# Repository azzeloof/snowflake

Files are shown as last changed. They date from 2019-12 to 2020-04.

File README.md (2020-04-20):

# snowflake
 A PCB holiday ornament with lots of blinking LEDs!

## Hardware
The board consists of twelve reverse-mounted LEDs [charlieplexed](https://en.wikipedia.org/wiki/Charlieplexing) and hooked up to an ATtiny85. Each LED is individually addressable, even though only four of the ATtiny's pins are being used (Charlieplexing is magic)! The board also has a pushbutton for switching between modes. The ornament is powered via six CR1225 batteries.

The final board isn't the most elegant thing- there are several zero-ohm jumpers, and there's even a "decorative" wire that wraps around the snowflake that is actually a ground line I didn't want to route across the front of the ornament.

There is also a mistake in the current board files- under each LED should be a rectangle on the f.mask layer so that the area below the LED is free of solder mask. Instead, the rectangle is a keepout zone, which is useless in this situation. My solution was to scrape the areas clear with a knife but I don't recommend it because FR4 dust is nasty. The better solution is to fix the board files before ordering.

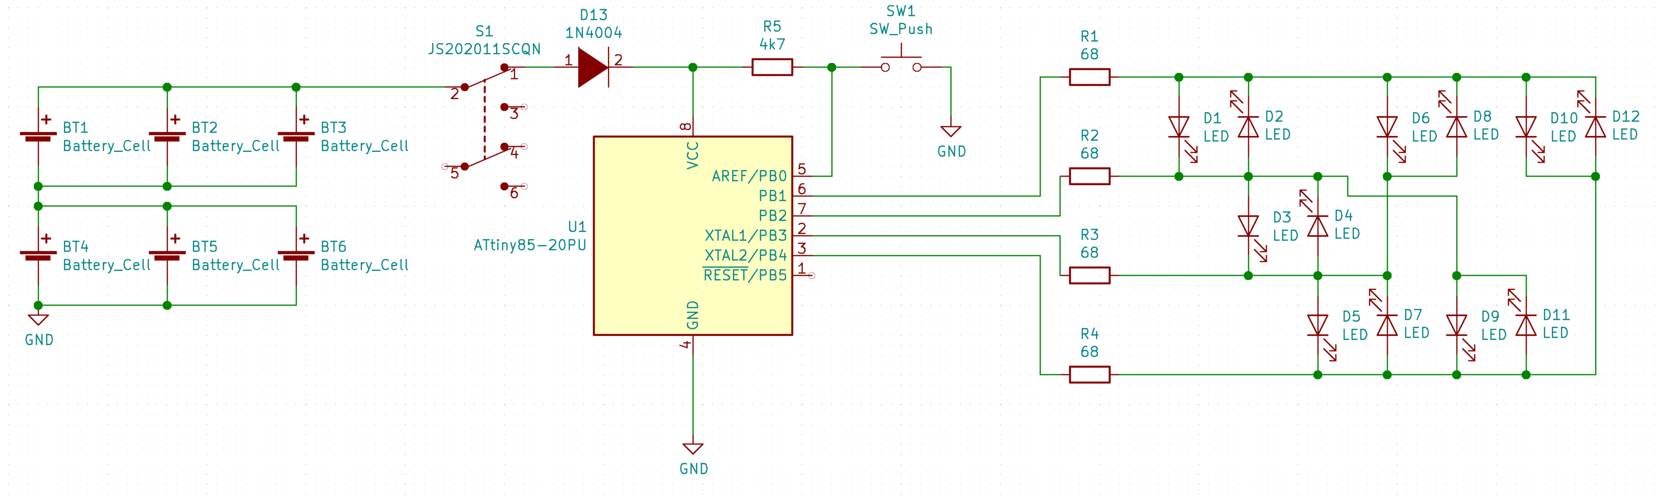
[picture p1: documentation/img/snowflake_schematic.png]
Snowflake Schematic


Board Front             |  Board Back
:-------------------------:|:-------------------------:
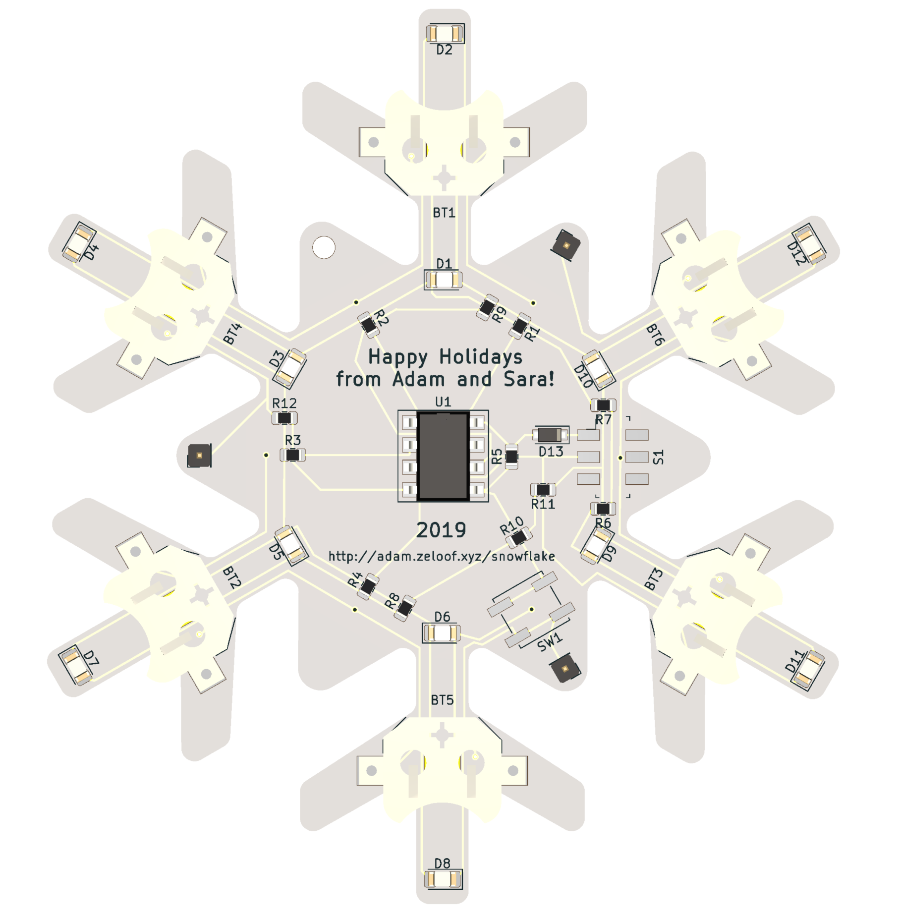
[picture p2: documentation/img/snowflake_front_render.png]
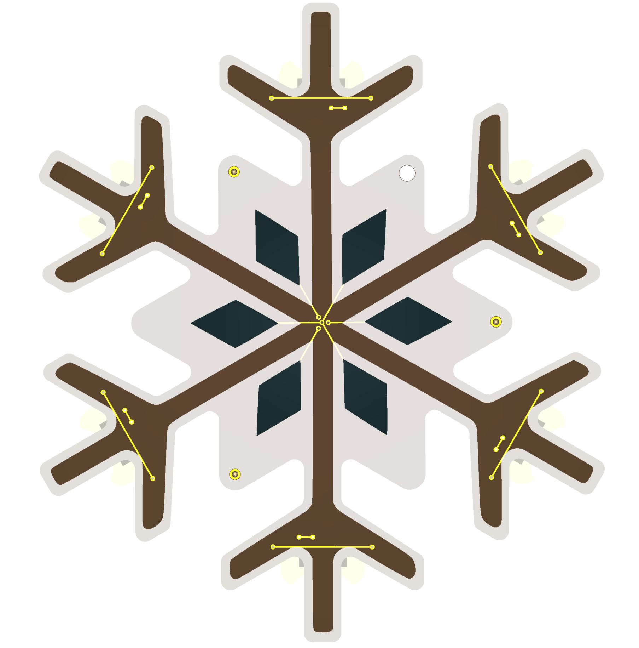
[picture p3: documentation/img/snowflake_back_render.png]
  |  

### BOM
A complete BOM can be found under [/documentation/snowflake_bom.csv](/documentation/snowflake_bom.csv), and can be uploaded to DigiKey for easy ordering. At the time of writing, the total DigiKey order is around $13. Boards can be ordered from anywhere that'll do white solder mask (I used PCBWay) and should be fairly cheap as well. You can order a stencil if desired, but I found it pretty easy to hand solder this one.

## (Firm?)(Soft?)ware
The ATtiny is programmed using the PlatformIO framework. Before programming, you need to write an Arduino bootloader to the chip using the Arduino IDE. When burning the bootloader, here are the settings we used:

+ Chip: "ATtiny85"
+ Clock: "8 MHz (internal)"
+ B.O.D: "B.O.D. Disabled"
+ Timer 1 Clock: "CPU"
+ LTO (1.6.11+ only): "Disabled"

The code is adapted from the wonderful work of David Johnson-Davies, published at http://www.technoblogy.com/show?2H0K.

To program the chips, we used SparkFun's [Pocket AVR Programmer](https://www.sparkfun.com/products/9825), but you should be able to use any programmer compatibe with the ATtiny85 (or just use an Arduino Uno!).

## Version History
Release 1.0 represents the snowflake ornaments as we initially made and distributed them. Once it is released, maybe we'll improve some stuff (but any hardware improvements will be untested).

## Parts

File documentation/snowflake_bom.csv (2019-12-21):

Manufacturer Part Number | Manufacturer | Digi-Key Part Number | Customer Reference | Reference Designator | Packaging | Part Status | Quantity | Unit Price | Extended Price | Quantity Available | Mfg Std Lead Time | Description | RoHS Status | Lead Free Status | REACH Status
ATTINY85-20PU | Microchip Technology | ATTINY85-20PU-ND |  |  | Tube | Active | 1 | 1.20000 | $1.20 | 424 | 7 Weeks | IC MCU 8BIT 8KB FLASH 8DIP | ROHS3 Compliant | Lead free | REACH Unaffected
114-87-308-41-134161 | Preci-Dip | 1212-1032-ND |  |  | Tube | Active | 1 | 0.57000 | $0.57 | 3379 | 10 Weeks | CONN IC DIP SOCKET 8POS GOLD | ROHS3 Compliant | Lead free | REACH Unaffected
JS202011SCQN | C&K | 401-2002-1-ND |  |  | Cut Tape (CT) | Active | 1 | 0.48000 | $0.48 | 63083 | 13 Weeks | SWITCH SLIDE DPDT 300MA 6V | ROHS3 Compliant | Lead free | REACH Unaffected
APTR3216PBC/A | Kingbright | 754-1169-1-ND |  |  | Cut Tape (CT) | Active | 12 | 0.47900 | $5.74 | 198739 | 9 Weeks | LED BLUE CLEAR CHIP SMD | ROHS3 Compliant | Lead free | REACH Unaffected
RMCF0805FT68R0 | Stackpole Electronics Inc | RMCF0805FT68R0CT-ND |  |  | Cut Tape (CT) | Active | 4 | 0.10000 | $0.40 | 54109 | 17 Weeks | RES 68 OHM 1% 1/8W 0805 | ROHS3 Compliant | Lead free | REACH Unaffected
RMCF0805ZT0R00 | Stackpole Electronics Inc | RMCF0805ZT0R00CT-ND |  |  | Cut Tape (CT) | Active | 7 | 0.10000 | $0.70 | 1039707 | 17 Weeks | RES 0 OHM JUMPER 1/8W 0805 | ROHS3 Compliant | Lead free | REACH Unaffected
RC0805FR-074K7L | Yageo | 311-4.70KCRCT-ND |  |  | Cut Tape (CT) | Active | 1 | 0.10000 | $0.10 | 4827587 | 16 Weeks | RES SMD 4.7K OHM 1% 1/8W 0805 | ROHS3 Compliant | Lead free | REACH Unaffected
PTS645SL50SMTR92 LFS | C&K | CKN9088CT-ND |  |  | Cut Tape (CT) | Active | 1 | 0.31000 | $0.31 | 123917 | 14 Weeks | SWITCH TACTILE SPST-NO 0.05A 12V | ROHS3 Compliant | Lead free | REACH Unaffected
3000 | Keystone Electronics | 36-3000-ND |  |  | Bulk | Active | 6 | 0.52000 | $3.12 | 4750 | 6 Weeks | BATTERY RETAINER COIN 12MM SMD | ROHS3 Compliant | Lead free | REACH Unaffected
SM4004PL-TP | Micro Commercial Co | SM4004PL-TPMSCT-ND |  |  | Cut Tape (CT) | Active | 1 | 0.20000 | $0.20 | 29958 | 12 Weeks | DIODE GEN PURP 400V 1A SOD123FL | ROHS3 Compliant | Lead free | REACH Unaffected

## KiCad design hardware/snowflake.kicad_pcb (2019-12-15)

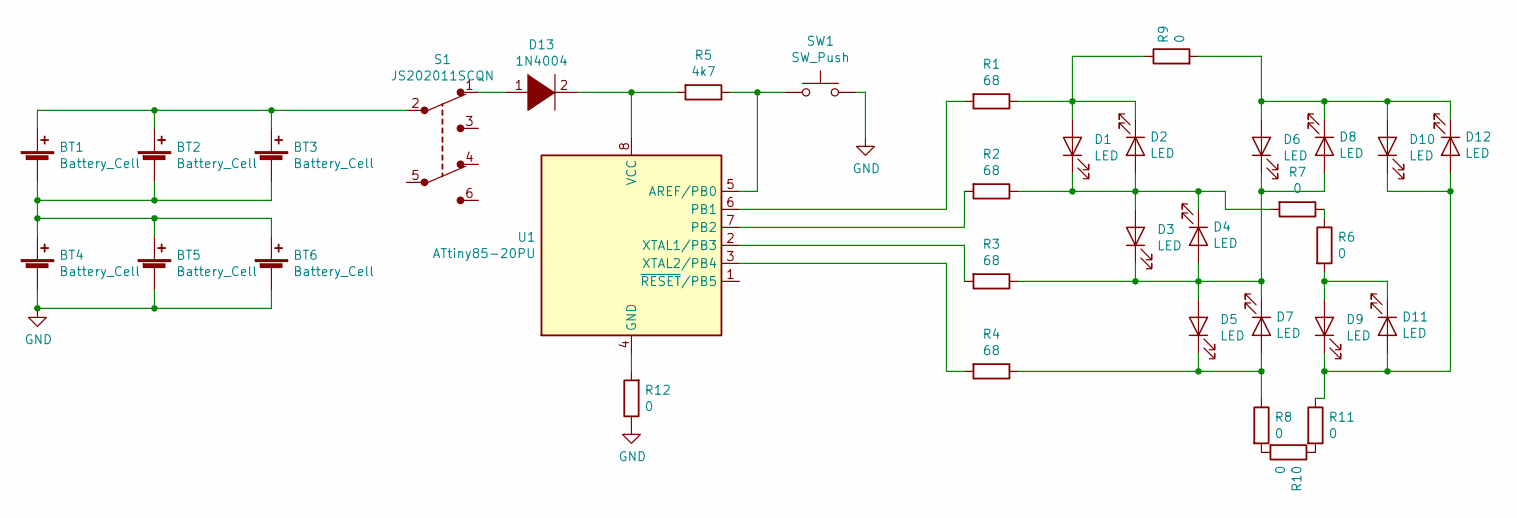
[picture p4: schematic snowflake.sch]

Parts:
BT1, BT2, BT3, BT4, BT5, BT6: Battery_Cell; BatteryHolder_Keystone_3000_1x12mm
D1, D2, D3, D4, D5, D6, D7, D8, D9, D10, D11, D12: LED; LED_1206_3216Metric
D13: 1N4004; D_SOD-123F
R1, R2, R3, R4: 68; R_0805_2012Metric
R5: 4k7; R_0805_2012Metric
R6, R7, R8, R9, R10, R11, R12: 0; R_0805_2012Metric
S1: JS202011SCQN; Switch_Slide_JS202011SCQN; MPN JS202011SCQN; Digi-Key_PN 401-2002-1-ND
SW1: SW_Push; SW_Push_1P1T_NO_CK_KSC6xxJ
U1: ATtiny85-20PU; DIP-8_W7.62mm_SMDSocket_SmallPads

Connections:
GND: BT4.2 (-), BT5.2 (-), BT6.2 (-), R12.1, SW1.2
unnamed: BT1.1 (+), BT2.1 (+), BT3.1 (+), S1.2
unnamed: BT1.2 (-), BT2.2 (-), BT3.2 (-), BT4.1 (+), BT5.1 (+), BT6.1 (+)
unnamed: D1.1 (K), D2.2 (A), D3.2 (A), D4.1 (K), R2.1, R7.2
unnamed: D1.2 (A), D2.1 (K), R1.1, R9.1
unnamed: D3.1 (K), D4.2 (A), D5.2 (A), D6.1 (K), D7.1 (K), D8.2 (A), R3.1
unnamed: D5.1 (K), D7.2 (A), R4.1, R8.1
unnamed: D9.1 (K), D10.1 (K), D11.2 (A), D12.2 (A), R11.1
unnamed: D6.2 (A), D8.1 (K), D10.2 (A), D12.1 (K), R9.2
unnamed: D9.2 (A), D11.1 (K), R6.2
unnamed: D13.1 (K), S1.1
unnamed: D13.2 (A), R5.2, U1.8 (VCC)
unnamed: R1.2, U1.6 (PB1)
unnamed: R2.2, U1.7 (PB2)
unnamed: R3.2, U1.2 (XTAL1/PB3)
unnamed: R4.2, U1.3 (XTAL2/PB4)
unnamed: R5.1, SW1.1, U1.5 (AREF/PB0)
unnamed: R6.1, R7.1
unnamed: R10.1, R11.2
unnamed: R8.2, R10.2
unnamed: R12.2, U1.4 (GND)

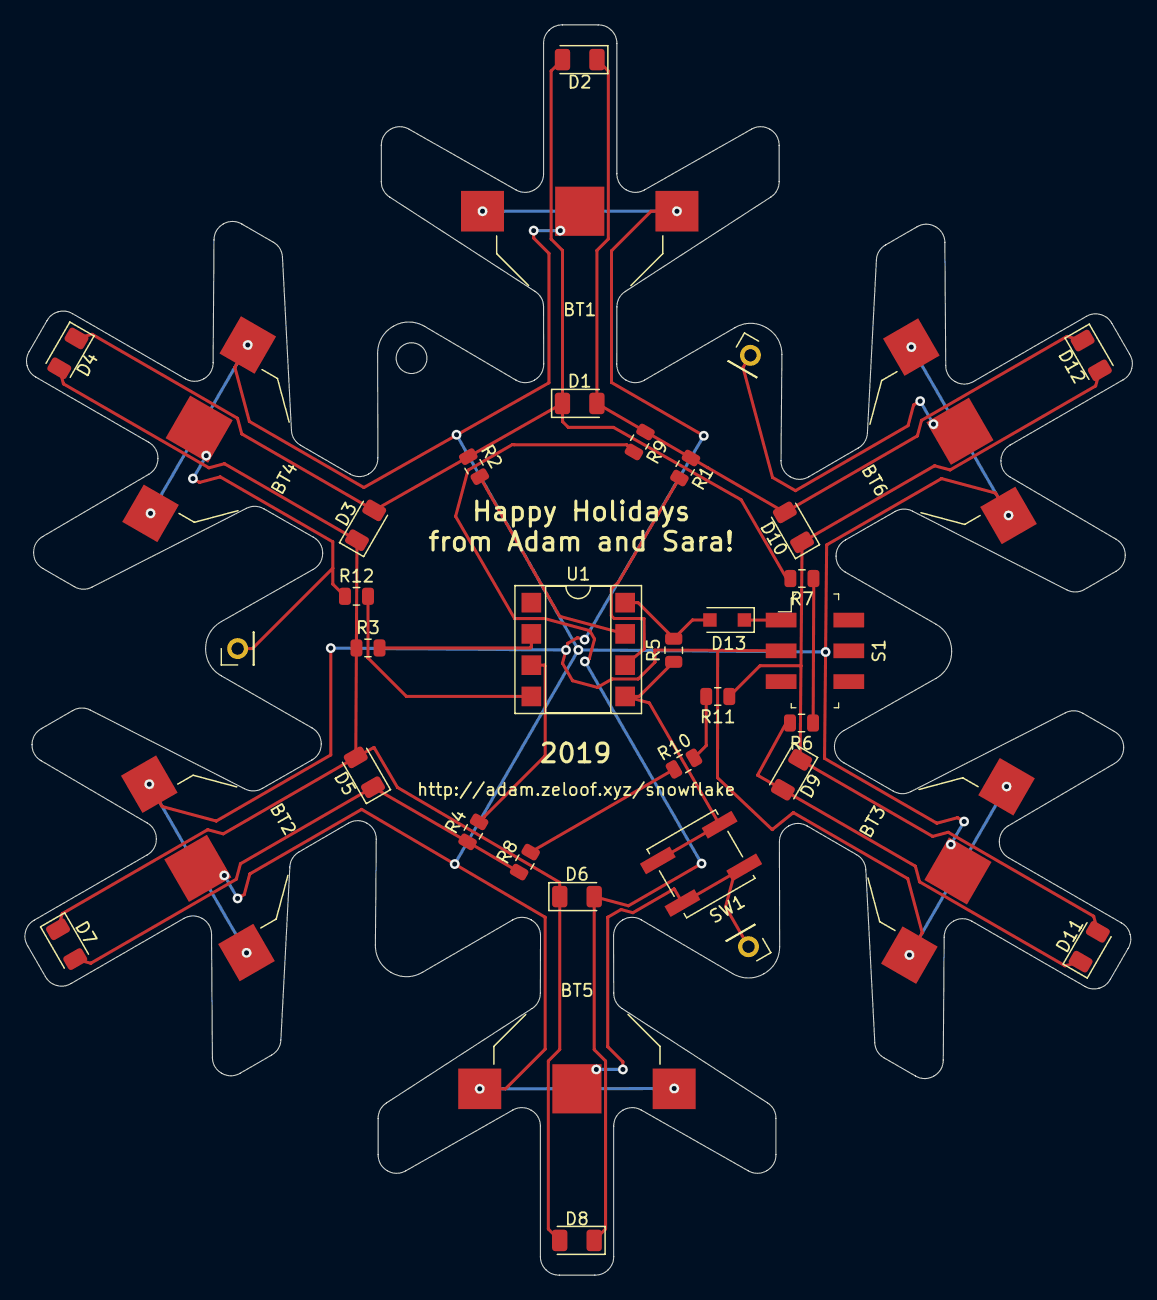
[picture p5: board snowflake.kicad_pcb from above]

Board: 2 copper layers, 90.0 x 101.6 mm, 34 parts (0 on the bottom side), 21 nets.

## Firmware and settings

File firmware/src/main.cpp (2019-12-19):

/*
 * Snowflake Christmas Ornament
 * 
 * Sara Adkins & Adam Zeloof - December 2019
 * 
 * PWM code adapted from David Johnson-Davies - www.technoblogy.com - 19th February 2017
 * http://www.technoblogy.com/show?2H0K
 */

#include "Arduino.h"
#include "modeButton.h"
#include "leds.h"
#include "ringFade.h"
#include "twinkle.h"
#include "chaos.h"

// Timer/Counter1 overflow interrupt
ISR(TIM1_COMPA_vect) {
  static uint8_t row, ramp, column, bits, colbit;
  ramp = (ramp+1) & 0x3F;             // Count from 0 to 63
  if (ramp == 0) {
    bits = 0x07; //0000111                    // All on
    column = (column + 1) & 0x03; // Count from 0 to 3
    row = column * 3;               //0 3 6 9
    colbit = 1<<(column+0); // 0b0001 0b0010 0b0100 0b1000
  }

  //check if check col has reached its ramp
  if (Level[row] == ramp) bits = bits & 0x06; // 00000110, mask out pos 0
  if (Level[row+1] == ramp) bits = bits & 0x05; // 00000101, mask out pos 1
  if (Level[row+2] == ramp) bits = bits & 0x03; // 00000011, mask out pos 2
  
  uint8_t mask = colbit - 1; 
  
  uint8_t outputs = (bits & mask) | (bits & ~mask)<<1;
  DDRB = (outputs | colbit) << 1;
  PORTB = (outputs) << 1;
}

void setup() {
  // Set up Timer/Counter1 to multiplex the LEDs
  TCCR1 = 1<<CTC1 | 2<<CS10;          // Divide by 2
  GTCCR = 0;                          // No PWM
  OCR1A = 0;
  OCR1C = 250-1;                      // 16kHz
  TIMSK = TIMSK | 1<<OCIE1A;          // Compare Match A interrupt

  setupButton();
  setupLeds();
}

void allOnProgram()
{
  allOn();
  checkButton();
}

void allOffProgram()
{
  clearLeds();
  checkButton();
}

void loop () {
  switch(mode) {
    case 0:
      fadeProgram();
      break;
    case 1:
      twinkleProgram(20, 200);
      break;
    case 2:
      allOnProgram();
      break;   
    case 3:
      chaosProgram(80,20);
      break; 
    default:
      allOffProgram();
      break;
  }
}

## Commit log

2019-12-16 Documentation Updates
    [snowflake_noJumpers.sch]
2019-12-16 recognize button press
2019-12-17 adding button press functionality
2019-12-19 fixed twinkle stall, added chaos mode
    [main.cpp]
2019-12-19 Flipped button state
2019-12-21 gitignore fix
    [snowflake_bom.csv]
